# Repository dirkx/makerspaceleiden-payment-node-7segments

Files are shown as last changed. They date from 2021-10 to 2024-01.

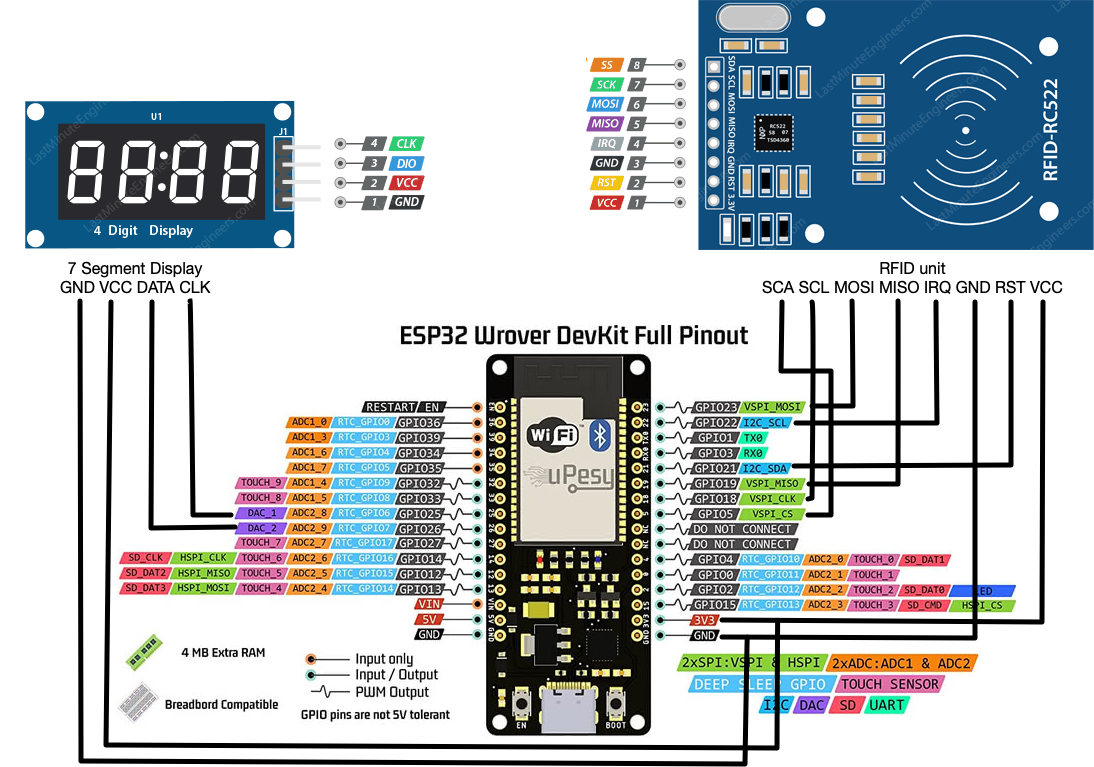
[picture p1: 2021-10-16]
wiring-rover.png

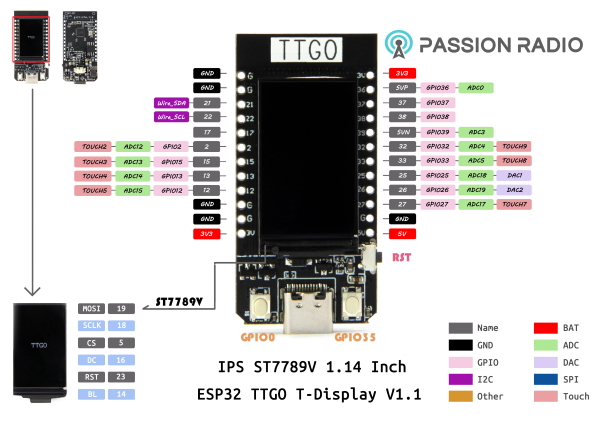
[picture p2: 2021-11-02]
pinmap-ttgo-esp32-ble.jpeg

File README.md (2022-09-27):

Rudimentary sketch for a payment terminal for the https://makerspaceleiden.nl/

Examples:

a. Pay for your beer or coffeee
	https://wiki.makerspaceleiden.nl/mediawiki/index.php/Payment_Terminal_with_4_seven_segment_displays
b. Pay for your heating
	https://wiki.makerspaceleiden.nl/mediawiki/index.php/NodeSpotHeating
c. Pay for things like wine, nuts, bolts, welding gas, etc
	https://wiki.makerspaceleiden.nl/mediawiki/index.php/Payment_Terminal_with_TFT_screen

How it al works
	https://wiki.makerspaceleiden.nl/mediawiki/index.php/SpaceTegoed

See https://github.com/dirkx/makerspaceleiden-payment-node-7segments/blob/main/schematic-7seg.pdf for a schematic
and https://vimeo.com/manage/videos/625531264 for the thing in use.

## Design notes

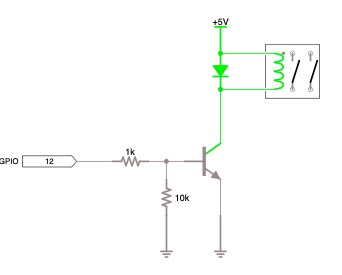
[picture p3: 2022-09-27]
schematic-spotheater.png

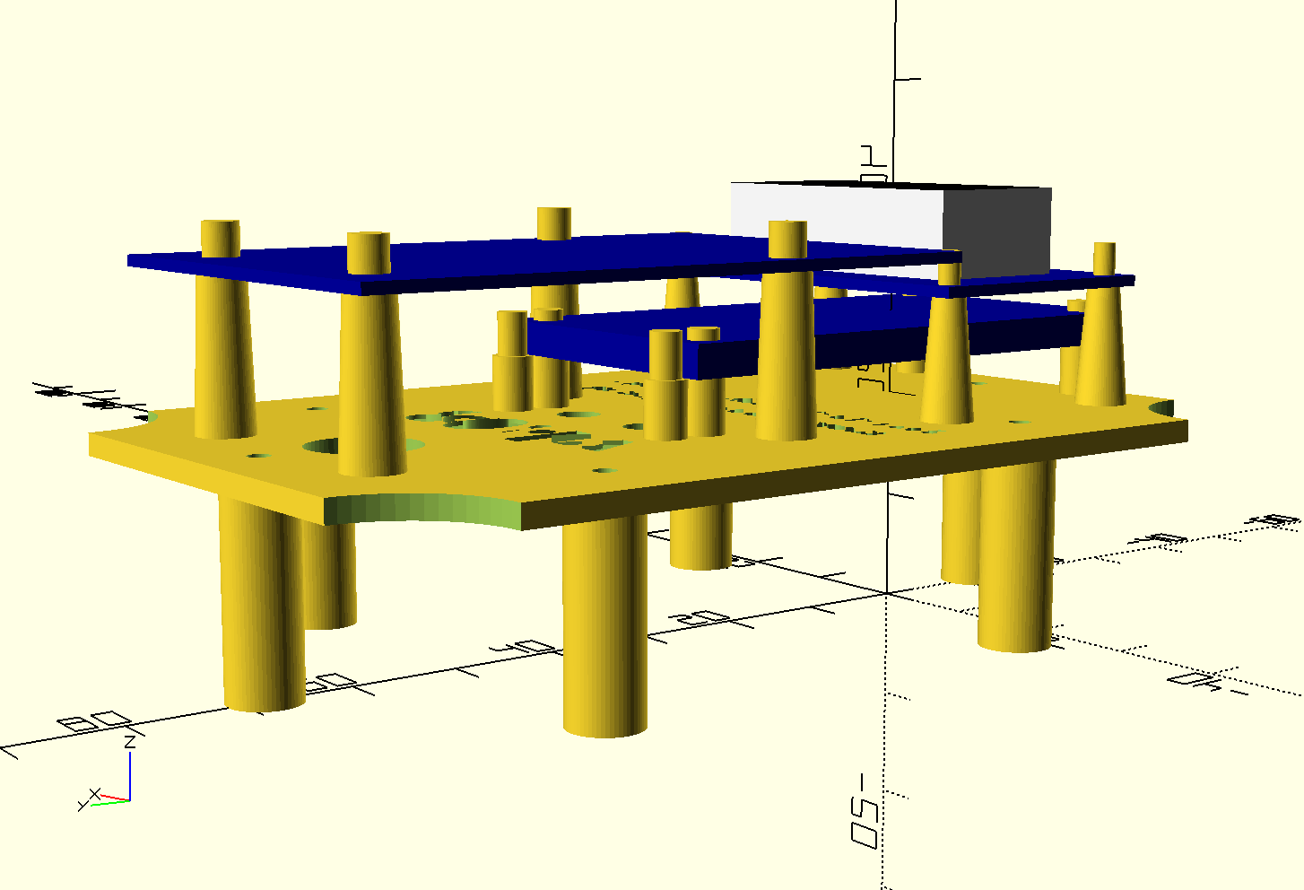
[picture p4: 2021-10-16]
enclosure.png

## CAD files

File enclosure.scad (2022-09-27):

$fn=60;

// Catalex 7 segement display
QUAD7_W=42;
QUAD7_H=24;
QUAD7_T=1;

QUAD7_DW=30;
QUAD7_DH=14;
QUAD7_DT=8;

QUAD7_HD=2;
QUAD7_HW=37.5;
QUAD7_HH=19.5;
QUAD7_HO=QUAD7_HD/2+1;
QUAD7_H_ASSYM=1;

showdev=0;
studs=0;
version="v1.05";

// Two sizes possible -- outside dimensions
//
box_h= 98; box_w = 68; //  98 x 68 x 48mm
// box_h=115; box_w = 90; // 115 x 90 x 55mm

box_t=2;        // thickness walls
box_space=1.5;  // space between the walls; as they are not that straight.


/*
   v1.01   white print 15/10/2021 for box with transparant cover.
   v1.02   scanner 1mm lower, whole plate 2mm lower, rfid pillars narrower
           pins display 0.5 mm to the inside in all directions. display
           display mm shifted to right for connector assymetry. text deeper
           and bolder.
   v1.03   Standoffs 2mm shorter.
   v1.04   Lowered main board by 2mm to prevent shorting 7x4 display 
           pins (Issue #2). Removed unused mid studs. Wider tiewrap
           holes for stud (Issue #3).
   v1.05   flag for the 'larger' boxes; not yet correct.
*/
module quad_holes(r=QUAD7_HD/2,h=10,top=1) {
   r2=r; r1=r*top;
   translate([QUAD7_HO,QUAD7_HO,-0.01]) cylinder(r2=r2,r1=r1,h=h);
   translate([QUAD7_W-QUAD7_HO,QUAD7_HO,-0.01]) cylinder(r2=r2,r1=r1,h=h);
   translate([QUAD7_W-QUAD7_HO,QUAD7_H-QUAD7_HO,-0.01]) cylinder(r2=r2,r1=r1,h=h);
   translate([QUAD7_HO,QUAD7_H-QUAD7_HO,-0.01]) cylinder(r2=r2,r1=r1,h=h);
};

module quad() {
   union() {
       difference() {
           color([0,0,0.6]) cube([QUAD7_W,QUAD7_H,QUAD7_T]); 
           quad_holes();
           }
       translate([(QUAD7_W-QUAD7_DW)/2, (QUAD7_H-QUAD7_DH)/2,QUAD7_T]) 
               color([1,1,1]) cube([QUAD7_DW,QUAD7_DH,QUAD7_DT]);
       translate([(QUAD7_W-QUAD7_DW)/2, (QUAD7_H-QUAD7_DH)/2,QUAD7_T+QUAD7_DT]) 
               color([0,0,0]) cube([QUAD7_DW,QUAD7_DH,0.01]);
   };
};


module display(h=10) {
translate([-QUAD7_W/2+QUAD7_H_ASSYM,-QUAD7_H/2,-(QUAD7_T+QUAD7_DT)]) {
   if (showdev>0) quad();
   translate([0,0,-h+4]) quad_holes(QUAD7_HD/2,h);
   translate([0,0,-h]) quad_holes(QUAD7_HD/2+0.5,h,1.6);
};
};

RC_H=59.5;
RC_W=39.5;
RC_T=1;

RC_HD=3.2;
RC_HW1=24.5; // top
RC_HW2=34.0; // near connector
RC_HH12=37.0; // between conectors.
RC_HT=5.0; // center to the top..

module rc_holes(r=RC_HD/2,h=10,top=1) {
   r2=r; r1=r*top;
   translate([(RC_W-RC_HW1)/2,RC_H-RC_HT,-0.01])
       cylinder(r2=r2,r1=r1,h=h);
   translate([(RC_W+RC_HW1)/2,RC_H-RC_HT,-0.01])
       cylinder(r2=r2,r1=r1,h=h);
   translate([(RC_W-RC_HW2)/2,RC_H-RC_HT-RC_HH12,-0.01])
       cylinder(r2=r2,r1=r1,h=h);
   translate([(RC_W+RC_HW2)/2,RC_H-RC_HT-RC_HH12,-0.01])
       cylinder(r2=r2,r1=r1,h=h);
};

module rc() {
   union() {
       difference() {
           color([0,0,0.6]) cube([RC_W,RC_H,RC_T]); 
           rc_holes();
           }
   };
};

module rfidall(h=10) {
translate([-RC_W/2,-RC_H/2,-RC_T]) {
   if (showdev>0) rc();
   translate([0,0,-h+4]) rc_holes(RC_HD/2,h);
   translate([0,0,-h]) rc_holes(RC_HD/2+0.5,h,1.25);
};
};


WR_H=52;    // WROOM_DEVKIT 1.1
WR_H2=56;   // ++ version
WR_W=28.5;
WR_HD=2.75;
WR_T=3;
WR_HO=(WR_W-23)/2;

module wroom_holes(r=WR_HD/2,h=10) {
   translate([WR_HO,WR_HO,-0.01]) cylinder(r=r,h=h);
   translate([WR_W-WR_HO,WR_HO,-0.01]) cylinder(r=r,h=h);
   translate([WR_W-WR_HO,WR_H-WR_HO,-0.01]) cylinder(r=r,h=h);
   translate([WR_HO,WR_H-WR_HO,-0.01]) cylinder(r=r,h=h);
   // for the large version
   translate([WR_W-WR_HO,WR_H2-WR_HO,-0.01]) cylinder(r=r,h=h);
   translate([WR_HO,WR_H2-WR_HO,-0.01]) cylinder(r=r,h=h);
};
module wroom() {    
   union() {
       difference() {
           color([0,0,0.6]) cube([WR_W,WR_H,WR_T]); 
           wroom_holes();
           }
   };
};
module wroom_all(h=10) {
translate([-WR_W/2,-WR_H/2,-WR_T]) {
   if (showdev>0) wroom();
   translate([0,0,-h+4]) wroom_holes(WR_HD/2,h);
   translate([0,0,-h]) wroom_holes(WR_HD/2+0.5,h);
};
};


MB_W=box_w-box_t*2-box_space*2;
MB_H=box_h-box_t*2-box_space*2;
MB_T=2;
MB_P=45;
MB_V=80;
MB_HH=2;
MB_I=10;
MB_STUD=6.5;

module mb_pins(r=MB_HH/2,h=MB_T+0.01) {
   translate([(MB_W-MB_P)/2,(MB_H-MB_P)/2,0]) {
       translate([0,0,-0.01]) cylinder(r=r,h=h);
       translate([MB_P,0,-0.01]) cylinder(r=r,h=h);
       translate([MB_P,MB_P,-0.01]) cylinder(r=r,h=h);
       translate([0,MB_P,-0.01]) cylinder(r=r,h=h);
   };
   if (0) translate([(MB_W)/2,(MB_H-MB_V)/2,0]) {
       translate([0,0,-0.01]) cylinder(r=r,h=h);
       translate([0,MB_V,-0.01]) cylinder(r=r,h=h);
   };
};

// Mounting board
module mb(h=10) {
   difference() {
       union() {
       cube([MB_W,MB_H,MB_T]);
       if (studs) translate([0,0,-h]) mb_pins(MB_STUD/2, h=h);
       }
       translate([0,0,-0.1]) cylinder(r=MB_I,h=MB_T+1);
       translate([MB_W,0,-0.1]) cylinder(r=MB_I,h=MB_T+1);
       translate([MB_W,MB_H,-0.1]) cylinder(r=MB_I,h=MB_T+1);
       translate([0,MB_H,-0.01]) cylinder(r=MB_I,h=MB_T+1);
       // drill holes
       translate([0,0,-h-2]) mb_pins(MB_HH/2, h=h+5);
       // wire hole
       translate([MB_W/2,MB_H-15,-0.01]) cylinder(r=5,h=3);
       // tiewrap holes
       translate([MB_W/2-10,MB_H-48,-0.01]) cylinder(r=2,h=3);
       translate([MB_W/2+10,MB_H-48,-0.01]) cylinder(r=2,h=3);
       translate([MB_W/2-5,MB_H-73,-0.01]) cylinder(r=2,h=3);
       translate([MB_W/2+5,MB_H-73,-0.01]) cylinder(r=2,h=3);


       translate([MB_W/2,MB_H-30,-0.4+MB_T]) 
           linear_extrude(height = 1)
           text(version,halign="center", valign="center",size=8,font="Gill Sans:style=Bold");
};
       translate([MB_W/2,MB_H-53,-0.1+MB_T]) 
           linear_extrude(height = 0.5)
           text("makerspaceleiden.nl",halign="center", valign="center",
                size=3,font="Gill Sans:style=Bold");
       translate([MB_W/2,MB_H-58,-0.1+MB_T]) 
           linear_extrude(height = 0.5)
           text("2021-10-15 / paymentnode",halign="center", valign="center",
                size=2.5, font="Gill Sans:style=Bold");

if (studs == 0) {
   translate([-70,0,0]) {
   difference() {
    mb_pins(MB_STUD/2, h=h);
    translate([0,0,-5]) mb_pins(MB_HH/2, h=h+10);
   };
};
};
};

module mountingboard(h=10) {
   translate([-MB_W/2,-MB_H/2,0]) {
   mb(h);
   // translate([0,0,-h+4]) mb_pins(WR_HD/2,h);
   // translate([0,0,-h]) mb_pins(WR_HD/2+0.5,h);
       };
};

PH=16; // package height/highest board.
IH=40; // insighed height

translate([0,0,IH]) 
   display(PH-3); 

translate([0,40,IH-QUAD7_DT+3]) 
   rfidall(PH+QUAD7_DT-8);

translate([0,9,IH-12]) 
   wroom_all(PH-9);

translate([0,28,IH-PH-8]) 
   mountingboard(IH-PH-8);

if (showdev==2)
   translate([-2,-22,0]) cube([5,5,IH]);    

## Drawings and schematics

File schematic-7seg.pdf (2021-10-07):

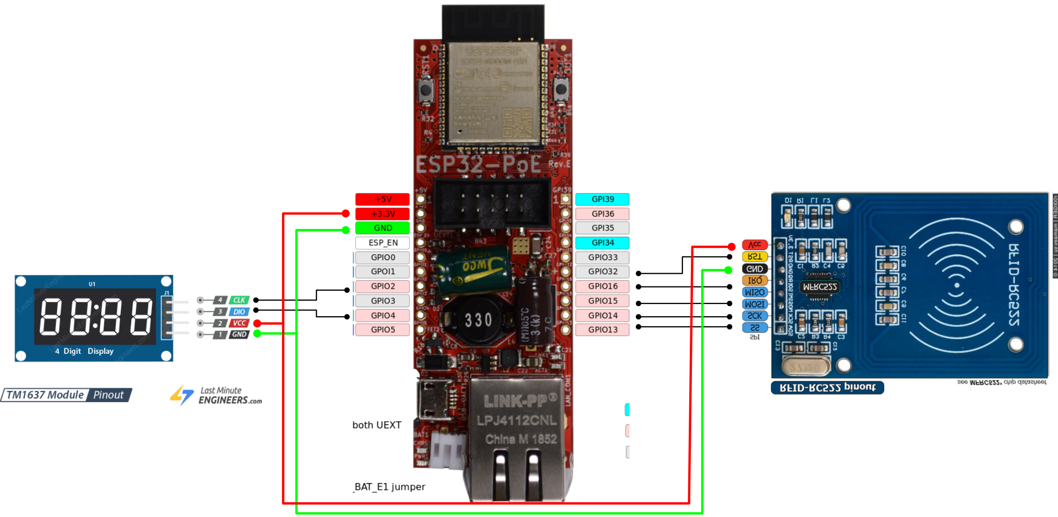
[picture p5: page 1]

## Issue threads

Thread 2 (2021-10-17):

7segment display cat touch metal cap ESP32

dirkx, 2021-10-17:
The entire mounting plate should be lowered by 1-2mm; as the longest pin on the 7 segment display get a little close to the metal cap of the ESP32 if it is not fully flush; and may cause a shortcut (all digits will then light up).

Closed 2021-10-17.

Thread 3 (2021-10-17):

Tiewrap holes to close together

dirkx, 2021-10-17:
Need 5-10mm extra space for the transformer.

Additonal set for the power cable not a bad idea either.

Closed 2021-10-17.

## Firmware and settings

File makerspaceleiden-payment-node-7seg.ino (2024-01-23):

// dirkx@webweaving.org, apache license, for the makerspaceleiden.nl
//
// Tools settings:
//  Board ESP32
//  Port: [the COM port your board has connected to]
//
// Boards used:
//    ESP32 WRover Module
//    MFRC522 (https://www.tinytronics.nl/shop/nl/communicatie-en-signalen/draadloos/rfid/rfid-kit-mfrc522-s50-mifare-met-kaart-en-key-tag)
//    7 segment display ( https://www.hobbyelectronica.nl/product/4-digit-klok-display-module)
//
// Heater module
//  ESP32 Dev Module
//  MFRC522
//  7 segment display
//  NPN transistor, 10k, 1k resistor
//  25Ampere, 5volt relay
//
// Additional Librariries (via Sketch -> library manager):
//    MFRC522-spi-i2c-uart-async
//    TM1637TinyDisplay
//    Arduino_JSON
//    PubSub (for MQTT)

#ifndef WIFI_NETWORK
#define WIFI_NETWORK "MyWifiNetwork"
#endif

#ifndef WIFI_PASSWD
#define WIFI_PASSWD "MyWifiPassword"
#error "You prolly do not want this!"
#endif

#include <WiFi.h>
#include <HTTPClient.h>
#include <WiFiClientSecure.h>
#include <Arduino_JSON.h>
#include <SPI.h>
#include <MFRC522.h>
#include <TM1637TinyDisplay.h>
#include <ESPmDNS.h>
#include <WiFiUdp.h>
#include <ArduinoOTA.h>

#include "global.h"
#include "log.h"
#include "rfid.h"
#include "rest.h"

#include "TelnetSerialStream.h"

// Wiring of 7 segment display - just
// two wires. See https://www.mcielectronics.cl/website_MCI/static/documents/Datasheet_TM1637.pdf
// and https://create.arduino.cc/projecthub/ryanchan/tm1637-digit-display-arduino-quick-tutorial-ca8a93
//
#define DISPLAY_CLK (25)
#define DISPLAY_DIO (26)

TM1637TinyDisplay display(DISPLAY_CLK, DISPLAY_DIO);

// For the heater
#define RELAY (12)

// Very ugly global vars - used to communicate between the REST call and the rest.
//
char terminalName[64] = TERMINAL_NAME;
int NA = 0;
char **amounts = NULL;
char **prices = NULL;
char **descs = NULL;
int amount = 0;
int default_item = -1;
double amount_no_ok_needed = AMOUNT_NO_OK_NEEDED;
const char * version = VERSION;
unsigned long device_specific_reboot_offset;
String label;
state_t md = BOOT;
double paid = 0;
unsigned long paid_seconds = 0;

int countdown = 0;

void setupDisplay() {
  display.setBrightness(BRIGHT_7);
  display.showString(VERSION);
  Log.println("Display set to " VERSION);
}

void setupRelay() {
  // relay is high-active; but there is a 10k
  // pulldown past the 1k driving resistor to
  // not let HiZ engage the relay.
  //
  digitalWrite(RELAY, 0);
  pinMode(RELAY, OUTPUT);
  digitalWrite(RELAY, 0);
}


void heatingOnOff(bool onOff) {
  digitalWrite(RELAY, onOff ? HIGH : LOW);
}

void setup()
{
  const char * p =  (const char*) __FILE__;
  if (rindex(p, '/')) p = rindex(p, '/') + 1;

  Serial.begin(115200);
  md = BOOT;

  byte mac[6];
  WiFi.macAddress(mac);
  snprintf(terminalName, sizeof(terminalName), "%s-%s-%02x%02x%02x", TERMINAL_NAME, 1 + VERSION, mac[3], mac[4], mac[5]);
  device_specific_reboot_offset = (*(unsigned short*)(mac + 4)) % 3600;

  Serial.print("\n\nBuild: " __DATE__ " " __TIME__ "\nUnit: ");
  Serial.println(terminalName);

  setupRelay();
  setupDisplay();
  setupAuth(terminalName);

  WiFi.mode(WIFI_STA);
  WiFi.begin(WIFI_NETWORK, WIFI_PASSWD);

  Log.print("Connecting to ");
  Log.println(WIFI_NETWORK);
  yield();

  display.showString("conn");

  WiFi.setHostname(terminalName);

  Log.print(terminalName);
  Log.println(" Wifi connecting");

  while (WiFi.waitForConnectResult() != WL_CONNECTED) {
    Log.println("Rebooting, wifi issue" );
    display.showString("FAIL");
    delay(5000);
    ESP.restart();
  };
  Log.println("Connected.");
  yield();

  setupLog();

  // try to get some reliable time; to stop my cert
  // checking code complaining.
  configTime(0, 0, NTP_SERVER);
  yield();

  Log.printf( "File:     %s\n", p);
  Log.println("Firmware: " TERMINAL_NAME "-" VERSION);
  Log.println("Build:    " __DATE__ " " __TIME__ );
  Log.print(  "Unit:     ");
  Log.println(terminalName);
  Log.print(  "MacAddr:  ");
  Log.println(WiFi.macAddress());
  Log.print(  "IP:       ");
  Log.println(WiFi.localIP());

  setupRFID();

  ArduinoOTA.setHostname(terminalName);
#ifdef OTA_HASH
  ArduinoOTA.setPasswordHash(OTA_HASH);
#else
#ifdef OTA_PASSWD
  ArduinoOTA.setPassword(OTA_PASSWD);
#endif
#endif

  ArduinoOTA
  .onStart([]() {
    display.showString("PROG");
    Log.println("OTA started");
  })
  .onEnd([]() {
    Log.println("OTA completed");
    // prevent a cleversod uplading a special binary. ignore the hardware/serial angle
    Log.println("OTA completed OK - need to wipe keystore before rebooting into new code.");
    wipekeys();
    display.showString("Done");
    log_stop();
    heatingOnOff(false);
  })
  .onProgress([](unsigned int progress, unsigned int total) {
    static int l = -100;
    int w = 100 * progress / total;
    if (w != l) {
      char fw[5];
      snprintf(fw, sizeof(fw), "F%3d", w);
      display.showString(fw);
    };
    l = w;
  })
  .onError([](ota_error_t error) {
    const char * label = "FO:OF";
    if (error == OTA_AUTH_ERROR) label = (const char*) "FO:AF";
    else if (error == OTA_BEGIN_ERROR) label = (const char*) "FO:BF";
    else if (error == OTA_CONNECT_ERROR) label = (const char*) "FO:CF";
    else if (error == OTA_RECEIVE_ERROR) label = (const char*) "FO:RF";
    else if (error == OTA_END_ERROR) label = (const char*)  "FO:EF";
    display.showString(label);
    Log.print("OTA error: E=");
    Log.print(error);
    Log.print(" - ");
    Log.println(label);
    delay(10 * 1000);
  });


  display.setBrightness(BRIGHT_HIGH / 3);
  display.showString("----");
  ArduinoOTA.begin();

  md = WAITING_FOR_NTP;
  Debug.println("Setup() complete. Starting loop");
}

static void loop_RebootAtMidnight() {
  static unsigned long lst = millis();
  if (millis() - lst < 60 * 1000)
    return;
  lst = millis();

  time_t now = time(nullptr);
  if (now < 3600)
    return;

#ifdef AUTO_REBOOT_TIME
  now += device_specific_reboot_offset;
  char * p = ctime(&now);
  //  0123456789012345678 9 0
  // "Thu Nov  4 09:47:43\n\0" -> 09:47\0
  p += 11;
  p[5] = 0;

  if (strncmp(p, AUTO_REBOOT_TIME, strlen(AUTO_REBOOT_TIME)) == 0 && millis() > 3600 * 1000 ) {
    Log.println("Nightly reboot - also to fetch new pricelist and fix any memory leaks.");
    heatingOnOff(false);
    ESP.restart();
  }
#endif
}

int checkcardswipe() {
  int v = 0;

  if (NA <= 0)
    return v;

  if (!loopRFID())
    return v;

  display.setBrightness(BRIGHT_HIGH);
  display.showString("[--]");

  int status = payByREST(tag, prices[amount], descs[amount]);

  if (status == 200) {
    display.showString("PAID");
    delay(500);
    paid += atof(prices[amount]);

    // bit of a hack - if the description is normal - things work as a one
    // off payment. But if the descripton starts with a number; then we assume
    // that this is a `timed in minutes' item. Annd we return how many seconds
    // the timer should be increased by.
    //
    // If the description is normal - the atoi() returns 0; so the function
    // will return zero.
    //
    v =  60 * atoi(descs[amount]);
    paid_seconds += v;
  } else {
    for (int i = 0; i < 4; i++) {
      display.showString("FAIL");
      delay(500);
      display.showNumber(status);
      delay(500);
    };
  };

  display.setBrightness(BRIGHT_HIGH / 3);
  display.showNumber(amount, 2);
  return v;
}

void loop()
{
  static unsigned long lst = millis();

  log_loop();
  ArduinoOTA.handle();
  loop_RebootAtMidnight();

  // flap relay every 5 seconds for testing.
  //
  if (0) {
    static unsigned long t = millis();
    if (millis() - t > 5000) {
      digitalWrite(RELAY, !digitalRead(RELAY));
      t = millis();
    }
  }

  switch (md) {
    case WAITING_FOR_NTP:
      display.showString("ntp");
      if (time(nullptr) > 3600)
        md = FETCH_CA;
      return;
      break;
    case FETCH_CA:
      display.showString("F CA");
      fetchCA();
      return;
    case REGISTER:
      display.showString("reg");
      registerDevice();
      return;
    case WAIT_FOR_REGISTER_SWIPE:
      display.showString("pair");
      if (loopRFID()) {
        display.showString("vrfy");
        registerDevice();
      };
      return;
    case REGISTER_PRICELIST:
      display.showString("F PL");
      if (fetchPricelist())
        md = ENTER_AMOUNT;
      else
        display.showString("Er:NA");
      return;
    case ENTER_AMOUNT:

      display.setBrightness(BRIGHT_HIGH / 3);
      display.showNumber(atof(prices[amount]), 2);
      // Bit of a hack - some swipes can return a number of seconds; when
      // they are not a one off payment for something - but entitle you to
      // something like 15 minutes of heating.
      // the value returned is in seconds.
      countdown +=  checkcardswipe();
      if (countdown > 0) {
        md = IN_COUNTDOWN;
        lst = millis();
      }
      break;
    case IN_COUNTDOWN:
      {
        // catch up as needed.
        while (millis() - lst >= 1000)
        {
          countdown--;
          lst += 1000;
        }

        // flash display 1.5 times towards the end
        if (countdown <= 60) {
          display.setBrightness(((millis() / 300) & 1) ? BRIGHT_HIGH : BRIGHT_1 );
        };

        if (countdown <= 0) {
          countdown = 0;

          // flash aggressivily once time is up.
          //
          for (int i = 0; i < 20; i++) {
            display.setBrightness((i & 1) ? BRIGHT_HIGH : BRIGHT_LOW);
            display.showString("0000");
            delay(120);
            display.showString("----");
            delay( 70);
          };

          // go back to normal, switch things off.
          //
          heatingOnOff(false);
          md = ENTER_AMOUNT;
          break;
        };

        // Check for a swipe while we are counting down, but do not reset millis().
        countdown += checkcardswipe();

        char timeleft[32];
        snprintf(timeleft, sizeof(timeleft) - 1, "%02d%02d", countdown / 60, countdown % 60);
        display.showString(timeleft, 4, 0 /*pos*/, 0b01000000 /* dots */);
        heatingOnOff(true);
        break;
      }
    case WIFI_FAIL_REBOOT:
      { static unsigned long last = millis();
        if (millis() - last > 10 * 1000)
          ESP.restart();
        display.showString("FFER");
      };
      break;
    default:
      break;
  };
}

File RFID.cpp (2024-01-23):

#include <SPI.h>
#include <MFRC522.h>

#include "global.h"
#include "log.h"

SPIClass * spi;
MFRC522_SPI * spiDevice;
MFRC522 * mfrc522;

char tag[128];
unsigned int rfid_scans = 0, rfid_miss = 0;

void setupRFID()
{
  unsigned char mac[6];
  const unsigned char  RFID_SCLK  =   18;
  const unsigned char  RFID_MISO  =   19;
  const unsigned char  RFID_MOSI  =   23;
  unsigned char        RFID_CS    =    5; // default VSPI wiring
  unsigned char        RFID_RESET =   21; // these two pins swapped on the older beer-node.
  unsigned char        RFID_IRQ   =   22;

  // 3C:71:BF:43:0F:E4 - oldest beer node with funny wiring.
  // Later units are as per above.
  WiFi.macAddress(mac);
  if (mac[3] == 0x43 && mac[4] == 0x0F  && mac[5] == 0xE4) {
    RFID_RESET =   22;
    RFID_CS    =   15;
    RFID_IRQ   =   21;
    Serial.println("WARNING: Beer node - changing RST/CS wiring");
  };

  spi = new SPIClass(VSPI);
  spi->begin(RFID_SCLK, RFID_MISO, RFID_MOSI, RFID_CS);

  spiDevice = new MFRC522_SPI(RFID_CS, RFID_RESET, spi);
  mfrc522 = new MFRC522(spiDevice);
  mfrc522->PCD_Init();

  Serial.print("RFID:     ");
  mfrc522->PCD_DumpVersionToSerial();  // Show details of PCD - MFRC522 Card Reader details
}

int loopRFID() {
  if ( ! mfrc522->PICC_IsNewCardPresent()) {
    return 0;
  }
  if ( ! mfrc522->PICC_ReadCardSerial()) {
    Log.println("Bad read (was card removed too quickly ? )");
    rfid_miss++;
    return 0;
  }
  if (mfrc522->uid.size < 3) {
    rfid_miss++;
    Log.println("Bad card (size tool small)");
    return 0;
  };

  // We're somewhat strict on the parsing/what we accept; as we use it unadultared in the URL.
  //
  if (mfrc522->uid.size > sizeof(mfrc522->uid.uidByte)) {
    rfid_miss++;
    Log.println("Too large a card id size. Ignoring.)");
    return 0;
  }

  memset(tag, 0, sizeof(tag));
  for (int i = 0; i < mfrc522->uid.size; i++) {
    char buff[5]; // 3 digits, dash and \0.
    snprintf(buff, sizeof(buff), "%s%d", i ? "-" : "", mfrc522->uid.uidByte[i]);
    strncat(tag, buff, sizeof(tag) - 1);
  };
  Log.println("Good scan");
  rfid_scans++;
  mfrc522->PICC_HaltA();
  return 1;
}

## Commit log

2021-10-07 Remove include that does not work for others.
    [makerspaceleiden-payment-node-7seg.ino]
2021-10-07 Wiring added
2021-10-16 Wiring simpler board with 3d printed mounting plate.
2021-10-16 Enclosure, corrected standoffs.
    [enclosure.scad]
2021-10-16 AS deployed.
    [enclosure.scad]
2021-10-17 Fix blank-out time to prevent reboots within the minute if the network is quiet
    [makerspaceleiden-payment-node-7seg.ino]
2021-10-17 Fixes issue #2 and #3 - more room for pints 7x4 board and wider transformer holes for tiewrap.
    [enclosure.scad]
2021-10-17 Also add enclosure file; for easy printing.
2021-10-17 Fix mac, fix setup signature
    [makerspaceleiden-payment-node-7seg.ino]
2021-10-18 Make blankout of reboot larger (repeat fix for issue #1); and make it random. Tag for v1.03
    [makerspaceleiden-payment-node-7seg.ino]
2021-10-19 Address issue #1 once more; replace the random by the mac-address to prevent a high/low number causing a second needless reboot & make the logs easier to understand
    [makerspaceleiden-payment-node-7seg.ino]
2021-10-20 Show name during DHCP, reboot on network fails.
    [makerspaceleiden-payment-node-7seg.ino]
2022-09-21 Early draft of heater node.
2022-09-27 Various tweaks for spot heater; version now as deployed in test unit; ready to be mounted. Assumes pin 25/26 to be corrected on the PCB during final install.
    [enclosure.scad]
2024-01-20 Update version number, give better error message on approved-but-not-yet assigned a station
    [RFID.cpp, makerspaceleiden-payment-node-7seg.ino]
